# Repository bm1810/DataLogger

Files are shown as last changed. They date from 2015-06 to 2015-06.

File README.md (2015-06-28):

# DataLogger
Development files for DataLogger project

-- SCRIPTS --
Development scripts can be accessed in the scripts folder. These should be uploaded to the Arduino to which the datalogger shield is connected

-- EAGLE --
The Eagle folder holds the Eagle cad files and drawing files to route the boards on an S63 milling machine.

-- BOXCAD --

This folder holds the 3D printer STL files and Solidworks CAD files from creation of the box.

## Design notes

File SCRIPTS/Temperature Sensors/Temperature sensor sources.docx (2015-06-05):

Temperature sensor sources

TMP36

Datasheet;

http://www.analog.com/static/imported-files/data_sheets/TMP35_36_37.pdf

Resources;

https://learn.adafruit.com/tmp36-temperature-sensor/using-a-temp-sensor

Dallas 18B20

Datasheet;

http://datasheets.maximintegrated.com/en/ds/DS18B20.pdf

Resources;

http://www.hacktronics.com/Tutorials/arduino-1-wire-tutorial.html

http://milesburton.com/Dallas_Temperature_Control_Library

http://playground.arduino.cc/Learning/OneWire

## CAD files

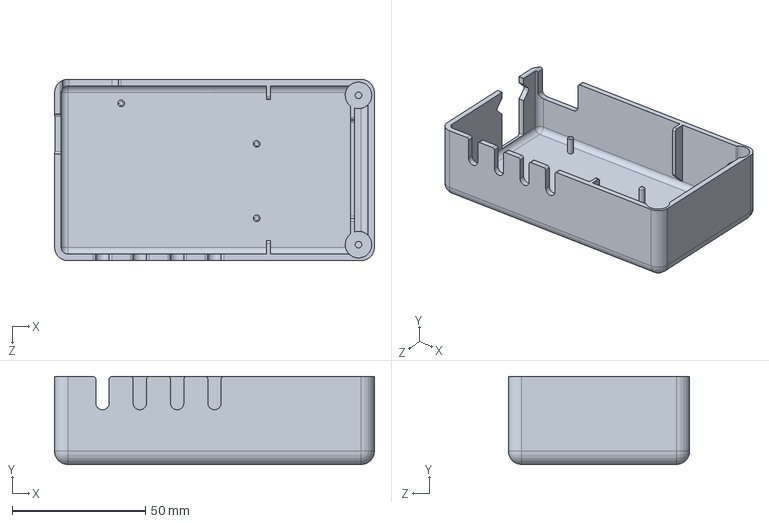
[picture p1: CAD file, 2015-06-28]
BOXCAD/Solidworks/BoxBase.SLDPRT
120.0 x 33.0 x 68.0 mm

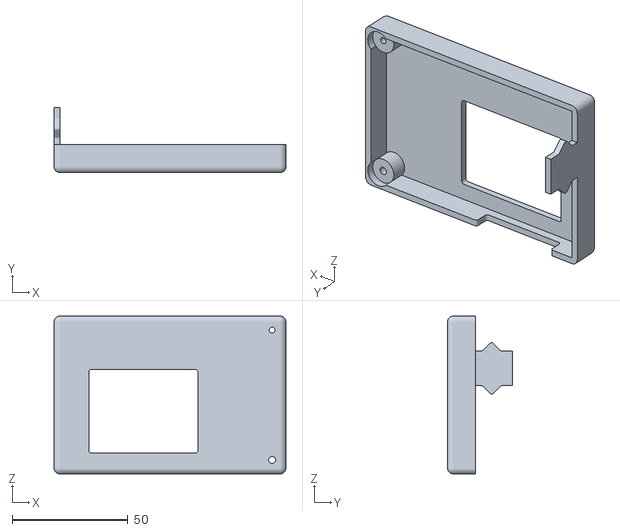
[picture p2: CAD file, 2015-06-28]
BOXCAD/Solidworks/BoxTop.STL
100.0 x 28.0 x 68.0

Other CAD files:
BOXCAD/3DPrint/BoxBase.STL
BOXCAD/3DPrint/BoxTop.STL

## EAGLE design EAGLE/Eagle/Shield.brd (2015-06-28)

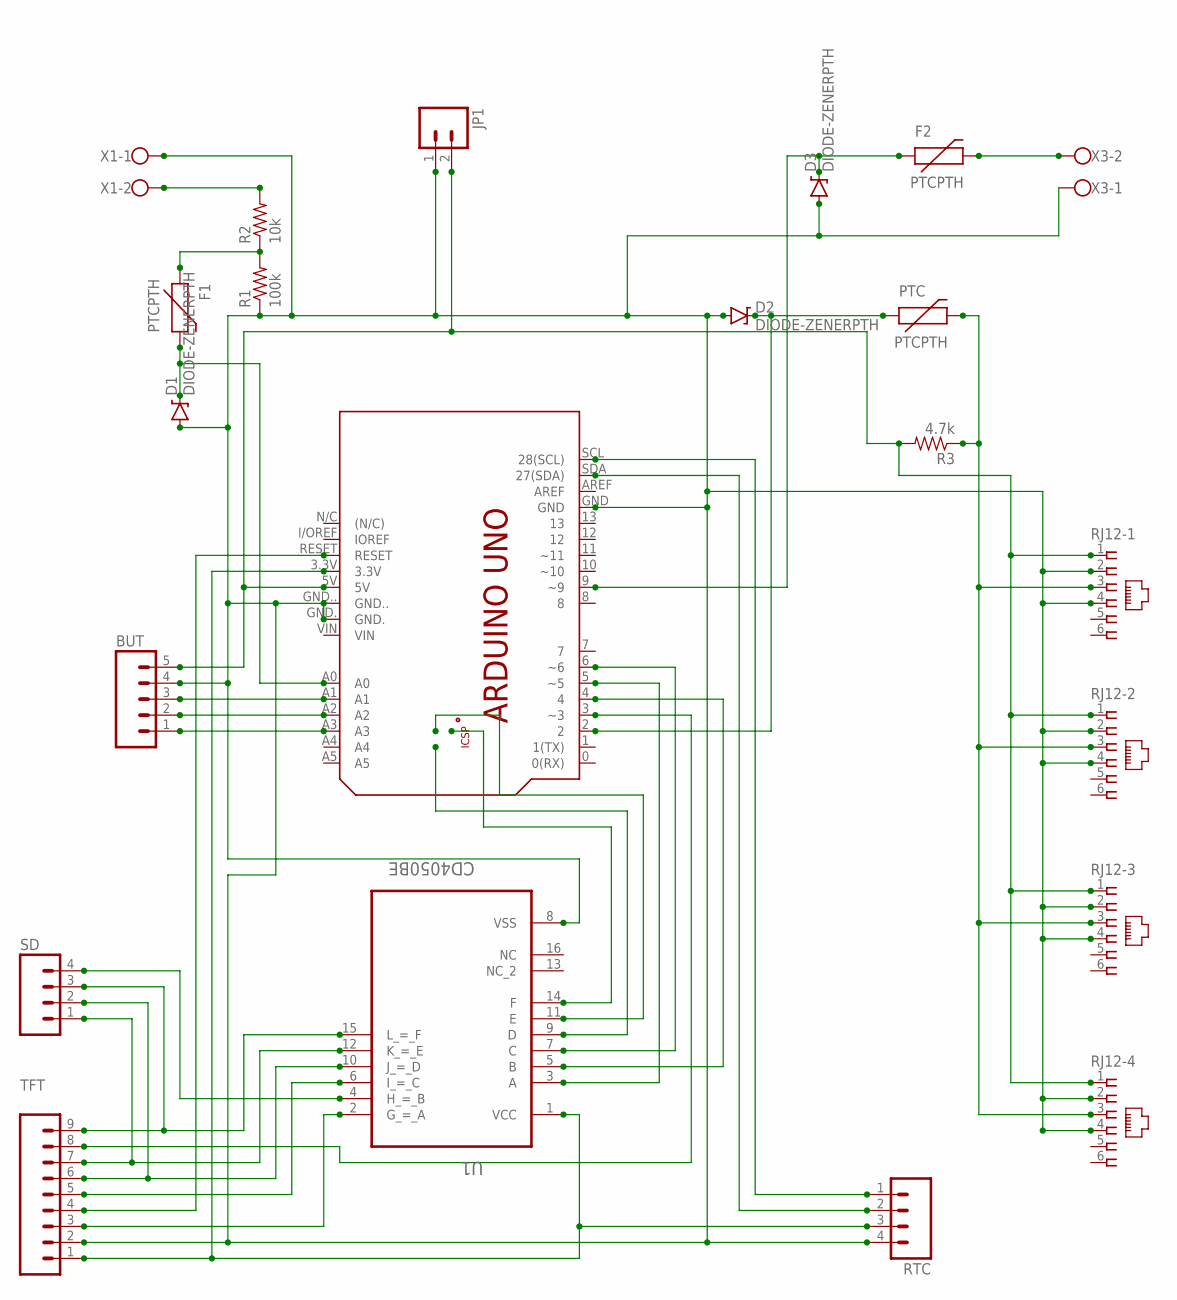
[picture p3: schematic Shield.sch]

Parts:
BUT: M05PTH_LONGPADS; 1X05_LONGPADS
D1, D2, D3: DIODE-ZENERPTH; DIODE-ZENER
F1, F2: PTCPTH; PTC
JP1: M023.5MM; SCREWTERMINAL-3.5MM-2
PCB1: ARDUINO_UNO
PTC: PTCPTH; PTC
R1: 100k; AXIAL-0.3
R2: 10k; AXIAL-0.3
R3: 4.7k; AXIAL-0.3
RJ12-1, RJ12-2, RJ12-3, RJ12-4: 555165-1
RTC: M04LONGPADS; 1X04_LONGPADS
SD: M04LONGPADS; 1X04_LONGPADS
TFT: M09LONGPADS; 1X09_LONGPADS
U1: CD4050BE; DIP254P762X508-16
X1, X3: W237-102

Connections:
GND: BUT.4, D1.P$2 (A), D2.P$2 (A), D3.P$2 (A), JP1.1, PCB1.GND, PCB1.GND., PCB1.GND.., R1.P$1 (1), RJ12-1.2, RJ12-1.4, RJ12-2.2, RJ12-2.4, RJ12-3.2, RJ12-3.4, RJ12-4.2, RJ12-4.4, RTC.4, TFT.2, U1.8 (VSS), X1.1, X3.1
unnamed: BUT.3, PCB1.A1
unnamed: PTC.P$2 (2), R3.P$1 (1), RJ12-1.3, RJ12-2.3, RJ12-3.3, RJ12-4.3
unnamed: PCB1.3.3V, RTC.3, TFT.1, U1.1 (VCC)
unnamed: D2.P$1 (C), PCB1.2, PTC.P$1 (1)
unnamed: PCB1.RESET, TFT.4
unnamed: SD.4, U1.4 (H_=_B)
unnamed: PCB1.5 (~5), U1.3 (A)
unnamed: PCB1.6 (~6), U1.7 (C)
unnamed: PCB1.MOSI, U1.9 (D)
unnamed: TFT.3, U1.2 (G_=_A)
unnamed: TFT.5, U1.6 (I_=_C)
unnamed: SD.2, TFT.6, U1.10 (J_=_D)
unnamed: PCB1.3 (~3), TFT.8
unnamed: SD.1, TFT.7, U1.12 (K_=_E)
unnamed: SD.3, TFT.9, U1.15 (L_=_F)
unnamed: PCB1.SCK, U1.11 (E)
unnamed: PCB1.MISO, U1.14 (F)
unnamed: BUT.5, JP1.2, PCB1.5V, R3.P$2 (2), RJ12-1.1, RJ12-2.1, RJ12-3.1, RJ12-4.1
unnamed: BUT.2, PCB1.A2
unnamed: PCB1.4, U1.5 (B)
unnamed: BUT.1, PCB1.A3
unnamed: PCB1.SDA (27(SDA)), RTC.2
unnamed: PCB1.SCL (28(SCL)), RTC.1
unnamed: F1.P$1 (1), R1.P$2 (2), R2.P$1 (1)
unnamed: D1.P$1 (C), F1.P$2 (2), PCB1.A0
unnamed: R2.P$2 (2), X1.2
unnamed: F2.P$2 (2), X3.2
unnamed: D3.P$1 (C), F2.P$1 (1), PCB1.9 (~9)

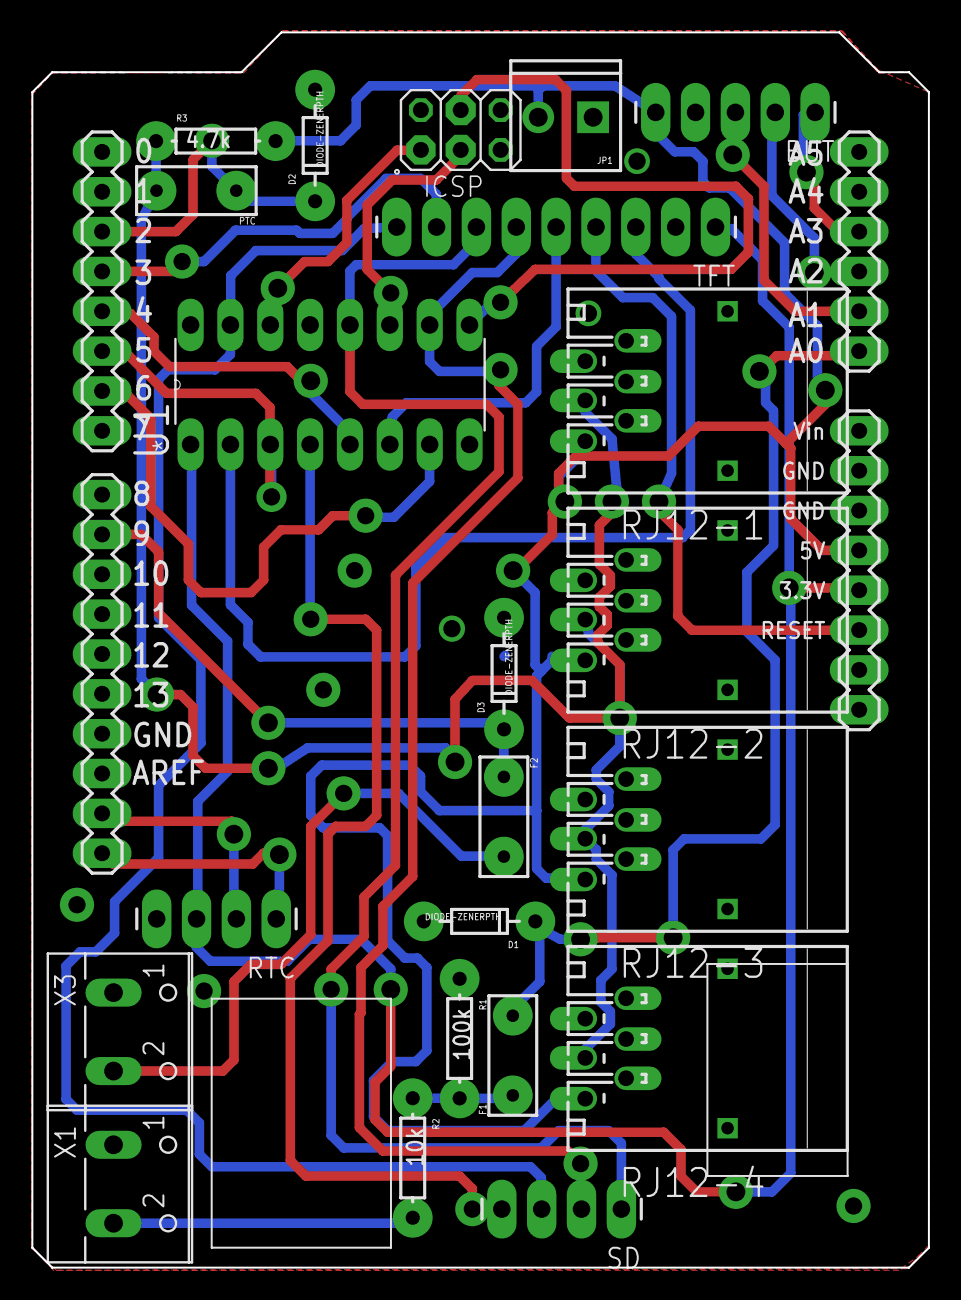
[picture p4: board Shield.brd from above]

Board: 2 copper layers, 57.1 x 78.7 mm, 22 parts (0 on the bottom side), 29 nets.

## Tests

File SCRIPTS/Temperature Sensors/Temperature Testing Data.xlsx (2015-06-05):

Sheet: Sheet1
Analogue Temperature:19.82 C | 19.82 | 19.82 | 1 | 19.82 |  | Digital Temperature:25.56 C | 25.56
Digital Temperature:20.37 C | 20.37 | 20.37 | 0 |  | 20.37 | Analogue Temperature:24.22 C | 24.22
Analogue Temperature:19.82 C | 19.82 | 19.82 | 1 | 19.82 |  | Digital Temperature:25.50 C | 25.50 | 19.82 | 20.37
Digital Temperature:20.44 C | 20.44 | 20.44 | 0 |  | 20.44 | Analogue Temperature:24.22 C | 24.22
Analogue Temperature:19.82 C | 19.82 | 19.82 | 1 | 19.82 |  | Digital Temperature:25.44 C | 25.44 | 19.82 | 20.44
Digital Temperature:20.37 C | 20.37 | 20.37 | 0 |  | 20.37 | Analogue Temperature:24.71 C | 24.71
Analogue Temperature:19.82 C | 19.82 | 19.82 | 1 | 19.82 |  | Digital Temperature:26.25 C | 26.25 | 19.82 | 20.37
Digital Temperature:20.44 C | 20.44 | 20.44 | 0 |  | 20.44 | Analogue Temperature:25.20 C | 25.20
Analogue Temperature:19.82 C | 19.82 | 19.82 | 1 | 19.82 |  | Digital Temperature:26.75 C | 26.75 | 19.82 | 20.44
Digital Temperature:20.44 C | 20.44 | 20.44 | 0 |  | 20.44 | Analogue Temperature:25.68 C | 25.68
Analogue Temperature:19.34 C | 19.34 | 19.34 | 1 | 19.34 |  | Digital Temperature:26.62 C | 26.62 | 19.34 | 20.44
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

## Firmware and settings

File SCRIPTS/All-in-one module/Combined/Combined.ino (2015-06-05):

/*

  Title:    Temperature, Voltage, LCD, RTC, SD card and Bluetooth Combined Script
  Author:   Ben Moffatt
  Date:     25/01/2015
  Version:  0.1

  Description:
    Combination of all previous scripts to record temperature and voltages
    simultaneously, stored with a real time and date. The data is recorded to the
    onboard SD card and transmitted over bluetooth.

  Acknowledgements:
    Digital temperature sensor: John Lowen http://www.vwlowen.co.uk/arduino/ds18b20/ds18b20.htm
    Thermocouple: http://playground.arduino.cc/Main/MAX6675Library
    SD Card: http://arduino.cc/en/Reference/SDCardNotes
    DS3231 RTC: https://github.com/JChristensen/DS3232RTC

*/

// ---------------------------LIBRARIES------------------------ //

// Temperature sensor libraries
#include <OneWire.h>
#include <DallasTemperature.h>
// RTC libraries
#include <DS3232RTC.h> 
#include <Time.h>
#include <Wire.h>  
// LCD Library
#include <PCD8544.h>
// MAX6675 Library (thermocouple)
#include <max6675.h>
//SD card and SPI libraries
#include <SD.h>
#include <SPI.h>

// ------------------------END OF LIBRARIES--------------------- //

// -------------------------DS18B20 SETUP---------------------- //

// Data wire is plugged into data pin 3 on the Arduino
#define ONE_WIRE_BUS 2
//Define the max number of DS18b20s
#define NumberOfDevices 2

// Setup a matrix in which to store digital sensor addresses
byte allAddress [NumberOfDevices][8];
// Declare variable to store number of One Wire devices
byte totalDevices;

// Setup a oneWire instance to communicate with any OneWire devices
OneWire oneWire(ONE_WIRE_BUS);
// Pass our oneWire reference to Dallas Temperature. 
DallasTemperature sensors(&oneWire);

// ---------------------END OF DS18B20 SETUP------------------ //

// -------------------------RTC SETUP------------------------- //

//Setup millisec value
volatile unsigned long millistart;
//Set up minute rollover. 61 is an impossible minute
byte minreg = 60;

// ---------------------END OF RTC SETUP---------------------- //

// -------------------------LCD SETUP------------------------- //

static PCD8544 lcd;
byte lineNo = 0;

// ---------------------END OF LCD SETUP---------------------- //

// -----------------------MAX6675 SETUP---------------------- //

//Set up the pins that the MAX6675 connects to
int thermoDO = 8;
int thermoCS = 9;
int thermoCLK = A0;

// Let library know which pins the thermocouple is conected to:
MAX6675 thermocouple(thermoCLK, thermoCS, thermoDO);

//Define what the thermocouple temperature will be
int tctemp = 0;

// --------------------END OF MAX6675 SETUP------------------ //

const int chipSelect = 10;

// ----------------------VOLTMETER SETUP--------------------- //

// number of analog samples to take per reading
#define NUM_SAMPLES 10
// reference voltage for the Arduino - MEASURE FOR ACCURACY
#define vPow 5.0
// resistance values - MEASURE FOR ACCURACY
#define r1 100000
#define r2 10000

// ------------------END OF VOLTMETER SETUP------------------ //

// -----------------------SD CARD SETUP---------------------- //

char folderName[18] = "";
File csvFile;

// -------------------END OF SD CARD SETUP------------------- //

// -----------------------OVERALL SETUP----------------------- //

void setup(void) {
//  Serial.begin(9600);		                                   // set up for error checking
  Wire.begin();				                                   // start the I2C interface

  lcd.begin(84, 48);		                                   // setup the LCD resolution
  lcd.setCursor(0, lineNo);                               // show setup text on LCD
  lcd.print("Starting up...");
  lineNo++;
//  lcd.setCursor(0, lineNo);                               // put cursor in next line
//  lcd.print("Discovered:");                                // list all connected sensors

  //For storing on our SD card, set up the column headers
  String dataString = "";
 
  dataString += "Time";
  dataString += ",";
 
  sensors.begin();	                                           // start all digital temperature sensors
  totalDevices = discoverOneWireDevices();     // get addresses of our one wire devices into allAddress array 
//  if(totalDevices > 0) { lineNo++; };                  // add a line if there are digital temperature sensors connected
//  lcd.setCursor(0, lineNo);
//  lcd.print(totalDevices);
//  lcd.print(" x DS18b20");
  for (byte i=0; i < totalDevices; i++) {            // find out the number of total temp sensors
  sensors.setResolution(allAddress[i], 12);       // and set the a to d conversion resolution of each
  dataString += "Digital Temp ";
  dataString += String(i);
  dataString += ",";
  }
/*
  if(thermocouple.readCelsius() != NAN) {
    lineNo++;
    lcd.setCursor(0, lineNo);                              // put cursor in next line
    lcd.print("Thermocouple");                           // thermocouple must be connected
    dataString += "Thermocouple";
    dataString += ",";
    sensorCount++;
  }

  if(analogRead(2) > 0) {
	lineNo++;
    lcd.setCursor(0, lineNo);                              // put cursor in next line
    lcd.print("Voltmeter");                                  // voltmeter must be connected
    dataString += "Voltmeter";
    dataString += ",";
    sensorCount++;
  }

  if(analogRead(4) > 0) {
    lineNo++;
    lcd.setCursor(0, lineNo);                              // put cursor in next line
    lcd.print("Analog Temp");                            // TMP36 must be connected
    dataString += "Analog Temp";
    dataString += ",";
    sensorCount++;
  }

  delay(2000);

  // If there are no sensors connected, tell the user to connect some!
  if(sensorCount=0) {
  lcd.print("No sensors detected. Reset to try again");
  return;
  }
*/
  //Set up the RTC

  lcd.clear();                                                    // clear the LCD ready for the next menu
  lineNo = 0;

  //Set the status of the interrupt pin
  pinMode(A3, INPUT);
  //Include an interrupt from the clock
  attachInterrupt(A3, SecIntrpt, RISING);
  //RTC.setAlarm(ALM1_EVERY_SECOND);
  setSyncProvider(RTC.get);   // the function to get the time from the RTC
  if(timeStatus() != timeSet) {
      lcd.print("Unable to sync with the RTC");
  } else {
      lcd.print("System time   set"); 
  }

  // wait for everything to stabilise
  delay(1500);

  //Setup the SD card
  lcd.print("Initializing ");
  lineNo++;
  lcd.setCursor(0, lineNo);
  lcd.print("SD card...");
  // make sure that the default chip select pin is set to
  // output, even if you don't use it:
  pinMode(10, OUTPUT);

  lcd.clear();                                                    // clear the LCD ready for the next menu
  lineNo = 0;

  // see if the card is present and can be initialized:
  if (!SD.begin(chipSelect)) {
    lcd.clear();
    lineNo = 0;
    lcd.setCursor(0,lineNo);
    lcd.println("SD Card failedor not present");
    // don't do anything more:
    return;
  }
  
  lineNo = 0;
  lcd.setCursor(0,lineNo);
  lcd.clear();
  lcd.print("SD card");
  lineNo++;
  lcd.setCursor(0,lineNo);
  lcd.print("initialized.");

  lcd.clear();                                                    // clear the LCD ready for the next menu
  lineNo = 0;

  //Setup the files and folder structure on the SD card
  //Folders are named by date
  //char* folderName; 
  sprintf(folderName,"%02d%02d%02d",year(),month(),day());
  Serial.println(folderName);
  if (SD.exists(folderName)) {
    //append on the filename to the buffer
    sprintf(folderName,"%c%02d%02d%02d/%02d%02d.csv",47,year(),month(),day(),hour(),minute());
    lcd.setCursor(0,lineNo);
    lcd.print("Creating");
    lcd.print(folderName);
    //Serial.print(folderName);
    csvFile = SD.open(folderName, FILE_WRITE);
    csvFile.println(dataString);
    csvFile.close();
  } else {
    SD.mkdir(folderName);
    //append on the filename to the buffer
    sprintf(folderName,"%c%02d%02d%02d/%02d%02d.csv",47,year(),month(),day(),hour(),minute());
    lcd.setCursor(0,lineNo);
    lcd.print("Creating ");
    lcd.print(folderName);
    //Serial.print(folderName);
    csvFile = SD.open(folderName, FILE_WRITE);
    csvFile.println(dataString);
    csvFile.close();
  }
  
  lcd.clear();                                                    // clear the LCD ready for the next menu
  lineNo = 0;
}


// --------------------END OF OVERALL SETUP------------------- //


// ---------------------------LOOP--------------------------- //

void loop() {

  // make a string for assembling the data to log:
  String dataString = "";
  
  //Only change the time at the top of the screen if the current minute is no longer the same as the minute value of the last loop:
  if(minreg != minute()) {
    minreg = minute();
    lcd.setCursor(0,lineNo);
    char datetime[16] = "";
    sprintf(datetime, "%02d/%02d/%02d %02d:%02d", day(), month(), year()%100, hour(), minute());
    lcd.print(datetime);
    dataString += datetime;
   }

  dataString += ",";
    
  // Sensors request:
  sensors.requestTemperatures();                // Initiate  temperature request to all devices

  // Print the temperature sensor output
  for (byte i=0; i < totalDevices; i++) {
    lineNo++;
    lcd.setCursor(0,lineNo);
    float tempDigi = sensors.getTempC(allAddress[i]);
    lcd.print(" DT");
    lcd.print(i);
    lcd.print(": ");
    lcd.print(tempDigi);
    lcd.print("C");
    
    dataString += tempDigi;
    dataString += ",";
  }


  //Thermocouple display
  float thermoc = thermocouple.readCelsius();
  lcd.setCursor(0,3);
  lcd.print(" TC1: ");
  lcd.print(thermoc);
  dataString += thermoc;
  dataString += ",";
  

  //Voltage display
 
  float calcVolt = findVoltage(vPow,r1,r2); 
  lcd.setCursor(0,4);

  lcd.print(" VM:  ");
  lcd.print(calcVolt);
  lcd.print(" V");
  dataString += calcVolt;
  dataString += ",";

  //Analog temperature sensor

  float anlTemp = analogueTemp(); 
  lcd.setCursor(0,5);
  lcd.print(" AT:  ");
  lcd.print(anlTemp);
  lcd.print("C");
  dataString += anlTemp;
  dataString += ",";
  
  csvFile = SD.open(folderName, FILE_WRITE);
  csvFile.println(dataString);
  csvFile.close();
  delay(10);

}

// -----------------------END OF LOOP----------------------- //



// ------------------------FUNCTIONS------------------------ //

// ----------Voltmeter---------- //

float findVoltage(float vPowa, float r1a, float r2a) {

 // calculate the real voltage
 float anavoltage = (analogRead(A2) * vPowa) / 1024.0;
 float voltage = anavoltage / ((float)r2a / ((float)r1a + (float)r2a));

 return voltage;
}


// -------End of  Voltmeter------ //

// ------------TMP37------------- //

float analogueTemp()
{
  // read the input on analog pin 0 (TMP36 input):
  int anlsensorValue = analogRead(A1);
  
  // Convert the input signal into a voltage
  float voltage = anlsensorValue * 5.0;
  voltage /= 1024.0;
  
  // convert the sensor value to temp in C
  float anlTemp = (voltage - 0.5)*100;
  return anlTemp;
}

// --------End of TMP36------- //

// ------------RTC------------ //

// Setup the RTC alarm


// Second counting interrupt
void SecIntrpt() {

  //Define the chip value of milliseconds at the start of the count
  millistart = millis();

}


// ---------End of  RTC--------- //


// ----------Onewire----------- //

byte discoverOneWireDevices() {
  byte j=0;                                    // search for one wire devices and
                                                   // copy to device address arrays.
  while ((j < NumberOfDevices) && (oneWire.search(allAddress[j]))) {        
    j++;
  }
  for (byte i=0; i < j; i++) {
    Serial.print("Device ");
    Serial.print(i);  
    Serial.print(": ");                          
    printAddress(allAddress[i]);                  // print address from each device address arry.
  }
  Serial.print("\r\n");
  return j                      ;                 // return total number of devices found.
}

void printAddress(DeviceAddress addr) {
  byte i;
  for( i=0; i < 8; i++) {                         // prefix the printout with 0x
      Serial.print("0x");
      if (addr[i] < 16) {
        Serial.print('0');                        // add a leading '0' if required.
      }
      Serial.print(addr[i], HEX);                 // print the actual value in HEX
      if (i < 7) {
        Serial.print(", ");
      }
    }
  Serial.print("\r\n");
}

void printTemperature(DeviceAddress addr) {
  float tempC = sensors.getTempC(addr);           // read the device at addr.
  if (tempC == -127.00) {
    Serial.print("Error getting temperature.");
  } else {
    Serial.print(tempC);                          // and print its value.
    Serial.print(" C (");
  }
}

// --------End of Onewire------- //


// ---------------------END OF FUNCTIONS--------------------- //

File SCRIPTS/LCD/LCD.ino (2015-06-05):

/*

		This library allows 74hc595 shift registers to be added to digital pins 8, 9 and 10
		Daisy chain to add more shift registers
		Code used under MIT licence
		Original Site: http://bildr.org/2011/02/74hc595/

*/

#include <Shifter.h>

// Define the shift register pins
#define SER_Pin    8  //pin 14 on the 75HC595
#define RCLK_Pin   9  //pin 12 on the 75HC595
#define SRCLK_Pin  10 //pin 11 on the 75HC595

// Define the LCD pins on the shift register
#define PIN_SCE   3
#define PIN_RESET 4
#define PIN_DC    2
#define PIN_SDIN  1
#define PIN_SCLK  0

#define LCD_C     LOW
#define LCD_D     HIGH

//Define number of pixels on the display
#define LCD_X     84
#define LCD_Y     48

//How many of the shift registers - change this
#define NUM_REGISTERS 1 
//initaize shifter using the Shifter library
Shifter shifter(SER_Pin, RCLK_Pin, SRCLK_Pin, NUM_REGISTERS); 

static const byte ASCII[][5] =
{
 {0x00, 0x00, 0x00, 0x00, 0x00} // 20  
,{0x00, 0x00, 0x5f, 0x00, 0x00} // 21 !
,{0x00, 0x07, 0x00, 0x07, 0x00} // 22 "
,{0x14, 0x7f, 0x14, 0x7f, 0x14} // 23 #
,{0x24, 0x2a, 0x7f, 0x2a, 0x12} // 24 $
,{0x23, 0x13, 0x08, 0x64, 0x62} // 25 %
,{0x36, 0x49, 0x55, 0x22, 0x50} // 26 &
,{0x00, 0x05, 0x03, 0x00, 0x00} // 27 '
,{0x00, 0x1c, 0x22, 0x41, 0x00} // 28 (
,{0x00, 0x41, 0x22, 0x1c, 0x00} // 29 )
,{0x14, 0x08, 0x3e, 0x08, 0x14} // 2a *
,{0x08, 0x08, 0x3e, 0x08, 0x08} // 2b +
,{0x00, 0x50, 0x30, 0x00, 0x00} // 2c ,
,{0x08, 0x08, 0x08, 0x08, 0x08} // 2d -
,{0x00, 0x60, 0x60, 0x00, 0x00} // 2e .
,{0x20, 0x10, 0x08, 0x04, 0x02} // 2f /
,{0x3e, 0x51, 0x49, 0x45, 0x3e} // 30 0
,{0x00, 0x42, 0x7f, 0x40, 0x00} // 31 1
,{0x42, 0x61, 0x51, 0x49, 0x46} // 32 2
,{0x21, 0x41, 0x45, 0x4b, 0x31} // 33 3
,{0x18, 0x14, 0x12, 0x7f, 0x10} // 34 4
,{0x27, 0x45, 0x45, 0x45, 0x39} // 35 5
,{0x3c, 0x4a, 0x49, 0x49, 0x30} // 36 6
,{0x01, 0x71, 0x09, 0x05, 0x03} // 37 7
,{0x36, 0x49, 0x49, 0x49, 0x36} // 38 8
,{0x06, 0x49, 0x49, 0x29, 0x1e} // 39 9
,{0x00, 0x36, 0x36, 0x00, 0x00} // 3a :
,{0x00, 0x56, 0x36, 0x00, 0x00} // 3b ;
,{0x08, 0x14, 0x22, 0x41, 0x00} // 3c <
,{0x14, 0x14, 0x14, 0x14, 0x14} // 3d =
,{0x00, 0x41, 0x22, 0x14, 0x08} // 3e >
,{0x02, 0x01, 0x51, 0x09, 0x06} // 3f ?
,{0x32, 0x49, 0x79, 0x41, 0x3e} // 40 @
,{0x7e, 0x11, 0x11, 0x11, 0x7e} // 41 A
,{0x7f, 0x49, 0x49, 0x49, 0x36} // 42 B
,{0x3e, 0x41, 0x41, 0x41, 0x22} // 43 C
,{0x7f, 0x41, 0x41, 0x22, 0x1c} // 44 D
,{0x7f, 0x49, 0x49, 0x49, 0x41} // 45 E
,{0x7f, 0x09, 0x09, 0x09, 0x01} // 46 F
,{0x3e, 0x41, 0x49, 0x49, 0x7a} // 47 G
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
};

void LcdCharacter(char character)
{
  LcdWrite(LCD_D, 0x00);
  for (int index = 0; index < 5; index++)
  {
    LcdWrite(LCD_D, ASCII[character - 0x20][index]);
  }
  LcdWrite(LCD_D, 0x00);
}

void LcdClear(void)
{
  for (int index = 0; index < LCD_X * LCD_Y / 8; index++)
  {
    LcdWrite(LCD_D, 0x00);
  }
}

void LcdInitialise(void)
{
  shifter.clear();
  shifter.setPin(PIN_RESET, LOW);
  shifter.setPin(PIN_RESET, HIGH);
  shifter.write();
  LcdWrite(LCD_C, 0x21 );  // LCD Extended Commands.
  LcdWrite(LCD_C, 0xB1 );  // Set LCD Vop (Contrast). 
  LcdWrite(LCD_C, 0x04 );  // Set Temp coefficent. //0x04
  LcdWrite(LCD_C, 0x14 );  // LCD bias mode 1:48. //0x13
  LcdWrite(LCD_C, 0x20 );  // LCD Basic Commands
  LcdWrite(LCD_C, 0x0C );  // LCD in normal mode.
}

void LcdString(char *characters)
{
  while (*characters)
  {
    LcdCharacter(*characters++);
  }
}

void shiftOutReg(uint8_t dataPin, uint8_t clockPin, uint8_t bitOrder, uint8_t val, uint8_t dc)
{
  uint8_t i;

  for (i = 0; i < 8; i++)  {
    if (bitOrder == LSBFIRST){
      shifter.clear();
      shifter.setPin(PIN_DC, dc);
      shifter.setPin(PIN_SCE, LOW);
      shifter.setPin(dataPin, !!(val & (1 << i)));
      shifter.write();
    } else {
       shifter.clear();
       shifter.setPin(PIN_DC, dc);
       shifter.setPin(PIN_SCE, LOW);
       shifter.setPin(dataPin, !!(val & (1 << (7 - i))));
       shifter.write();

       shifter.setPin(clockPin, HIGH);
       shifter.write();
       shifter.setPin(clockPin, LOW);
       shifter.write();
    }
  }
  shifter.setPin(PIN_SCE, HIGH);
  shifter.write();
}


void LcdWrite(byte dc, byte data)
{
  shiftOutReg(PIN_SDIN, PIN_SCLK, MSBFIRST, data, dc);
}



void setup(void){
  
  //reset all register pins
  shifter.clear(); //set all pins on the shift register chain to LOW
  shifter.write(); //send changes to the chain and display them
  delay(1000);
  
  LcdInitialise();
  LcdClear();
  LcdString("Hello World!");
}               


void loop(){

}

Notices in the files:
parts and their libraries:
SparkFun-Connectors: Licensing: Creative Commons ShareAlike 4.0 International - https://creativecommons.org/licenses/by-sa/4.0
